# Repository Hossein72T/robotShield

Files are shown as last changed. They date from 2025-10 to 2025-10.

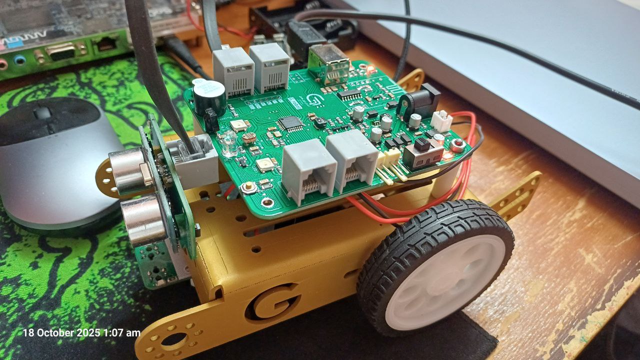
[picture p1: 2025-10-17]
docs/Ultasonic/Gro.jpg

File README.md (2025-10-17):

# Robot Shield Project

This project is part of the ZLab hardware assessment.

It includes:
- An **Arduino program** for reading distance using the **HC-SR05 ultrasonic sensor**
- A **custom library** written without using any external ultrasonic libraries
- A **PCB design** created in **Altium Designer** based on the **ATmega328** microcontroller

---

## Tools Used
- Arduino IDE  
- Altium Designer  

---

## Project Structure
```
robotShield/
 ├── code/           # Arduino sketches and custom library
 ├── pcb/            # Altium schematic and PCB files
 ├── docs/           # Report and screenshots
 └── README.md
```

---

## Project Contents
- `code/` → Arduino code and ultrasonic sensor library  
- `pcb/` → Altium schematic and PCB files  
- `docs/` → Report and related images  
- `README.md` → This file

---

Author: **Hossein Taghiloo**

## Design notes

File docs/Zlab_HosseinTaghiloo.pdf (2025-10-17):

گزارش عملکرد پروژههای ارزیابی

نام :حسین تقیلو
تاریخ :مهر ۱۴۰۴

۱ .راهاندازی سنسور اولتراسونیک05SRF

در این بخش، هدف راهاندازی و تست سنسور فاصلهسنج 05SRFبدون استفاده از الیبرری های آماده بود.

برای این منظور، یک کتابخانه اختصاصی با زبان ++C طراحی و پیادهسازی شد که شامل سه تابع اصلی است:

- ()getDistanceبرای محاسبه فاصله بر حسب سانتیمتر
- (thresholdCM(isObjectDetectedبرای تشخیص وجود جسم در فاصله مشخص
- ()getFilteredDistanceبرای میانگینگیری چند نمونه و کاهش نویز

کد در محیط IDE Arduinoنوشته و روی ربات GROکه خودم طراحی کردهام، تست عملی انجام شد. نتایج اندازهگیری دقیق و پایدار بودند و عملکرد سنسور در محدوده ۱۰ تا ۱۰۰ سانتیمتر بهدرستی تأیید شد.

کلیهی فایلهای مربوط به این بخش شامل کد منبع، فایلهای ino،. h.و cpp.در مخزن گیتهاب زیر قرار داده شدهاند: github.com/Hossein72T/robotShield

۲ .طراحی مدار و PCB شیلد ربات

در بخش دوم، طراحی مدار و برد مربوط به شیلد ربات انجام شد. برد بر پایهی میکروکنترلر P328ATmega طراحی شده تا از طریق IDE Arduinoقابل برنامهریزی باشد.

مدار شامل بخشهای زیر است:

- مدار تغذیه ۱۲ ولت با رگوالتور ۵ ولت
- کلید روشن/خاموش و ۵ دکمه فشاری برای کنترل حالتها
- نمایشگر OLED جهت نمایش وضعیت ها
- بازر ۵ ولتی برای هشدار صوتی
- ورودی سنسور و خروجی های کنترلی برای موتور و ماژولها

با توجه به محدودیت زمان، مسیرکشی برد بهصورت دستی انجام نشد و از قابلیت Route Autoنرمافزار Altium Designerاستفاده گردید.

با این حال، طراحی شماتیک، نتنامها، اتصاالت و ماژولهای مدار بهصورت کامل انجام شده و آمادهی ویرایش یا بازطراحی دستی هستند.

فایلهای پروژه شامل موارد زیر در مخزن گیتهاب در دسترس هستند: robotShield.PrjPcb, robotShield.PcbDoc, robotShield_CPU.SchDoc, وrobotShield_Power.SchDoc, robotShield_OLED.SchDoc, robotShield_USB.SchDoc robotShield_Buttom.SchDoc

۳ .جمعبندی

هر دو تسک خواسته شده مطابق شرح پروژه انجام و مستند شدند:

- پیادهسازی و تست موفق سنسور 05SRF بر روی ربات طراحیشده
- طراحی کامل مدار و برد شیلد ربات درDesigner Altium
- استفاده از Routing Auto بهدلیل محدودیت زمانی

تمامی فایلها و کدها از طریق مخزن زیر قابل مشاهده هستند: https://github.com/Hossein72T/robotShield

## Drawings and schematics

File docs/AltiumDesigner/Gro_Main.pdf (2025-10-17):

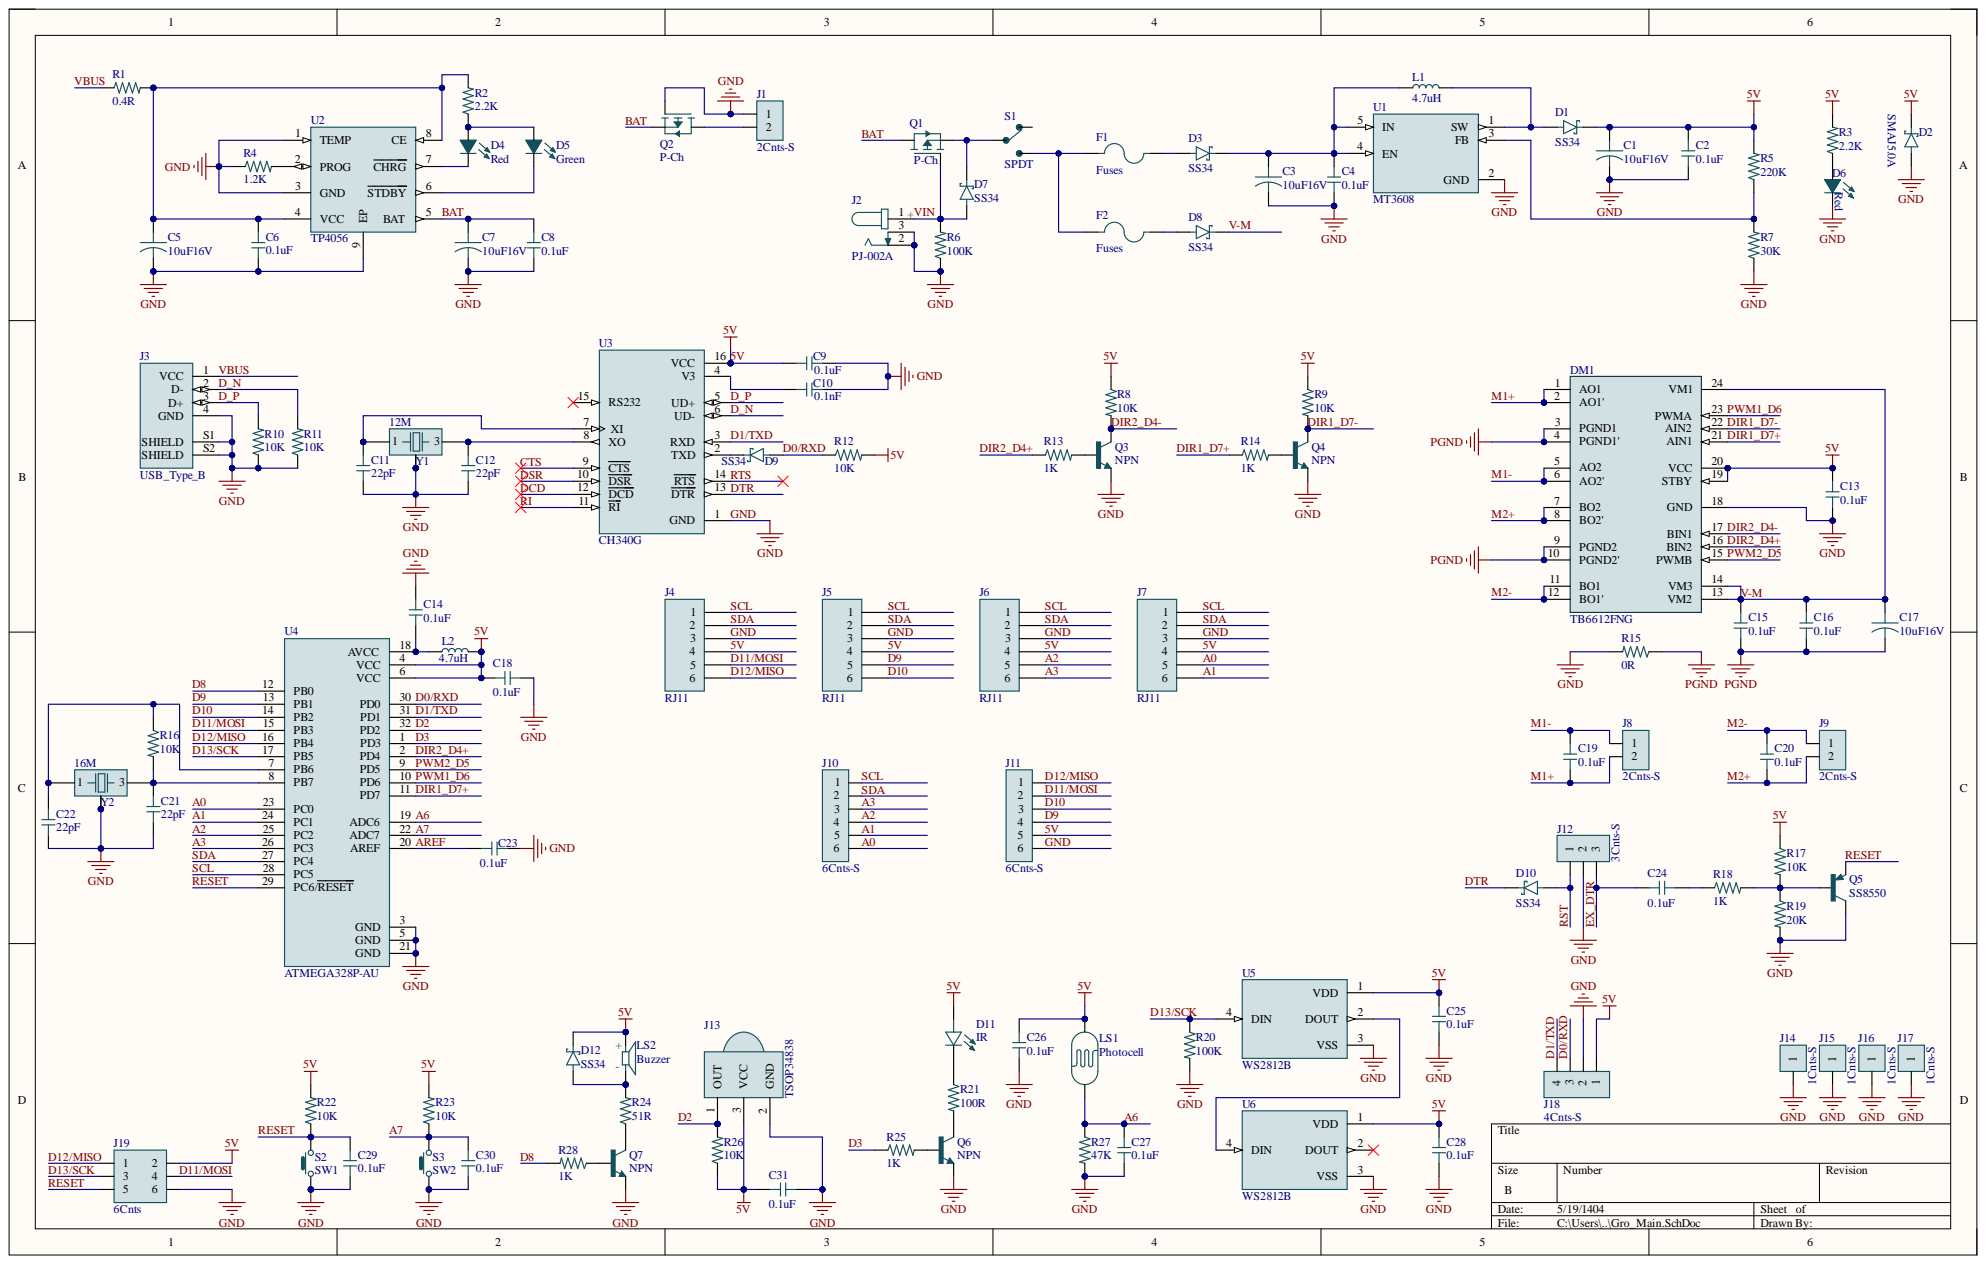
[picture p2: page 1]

SDA | SDA | SDA
GND | GND | GND

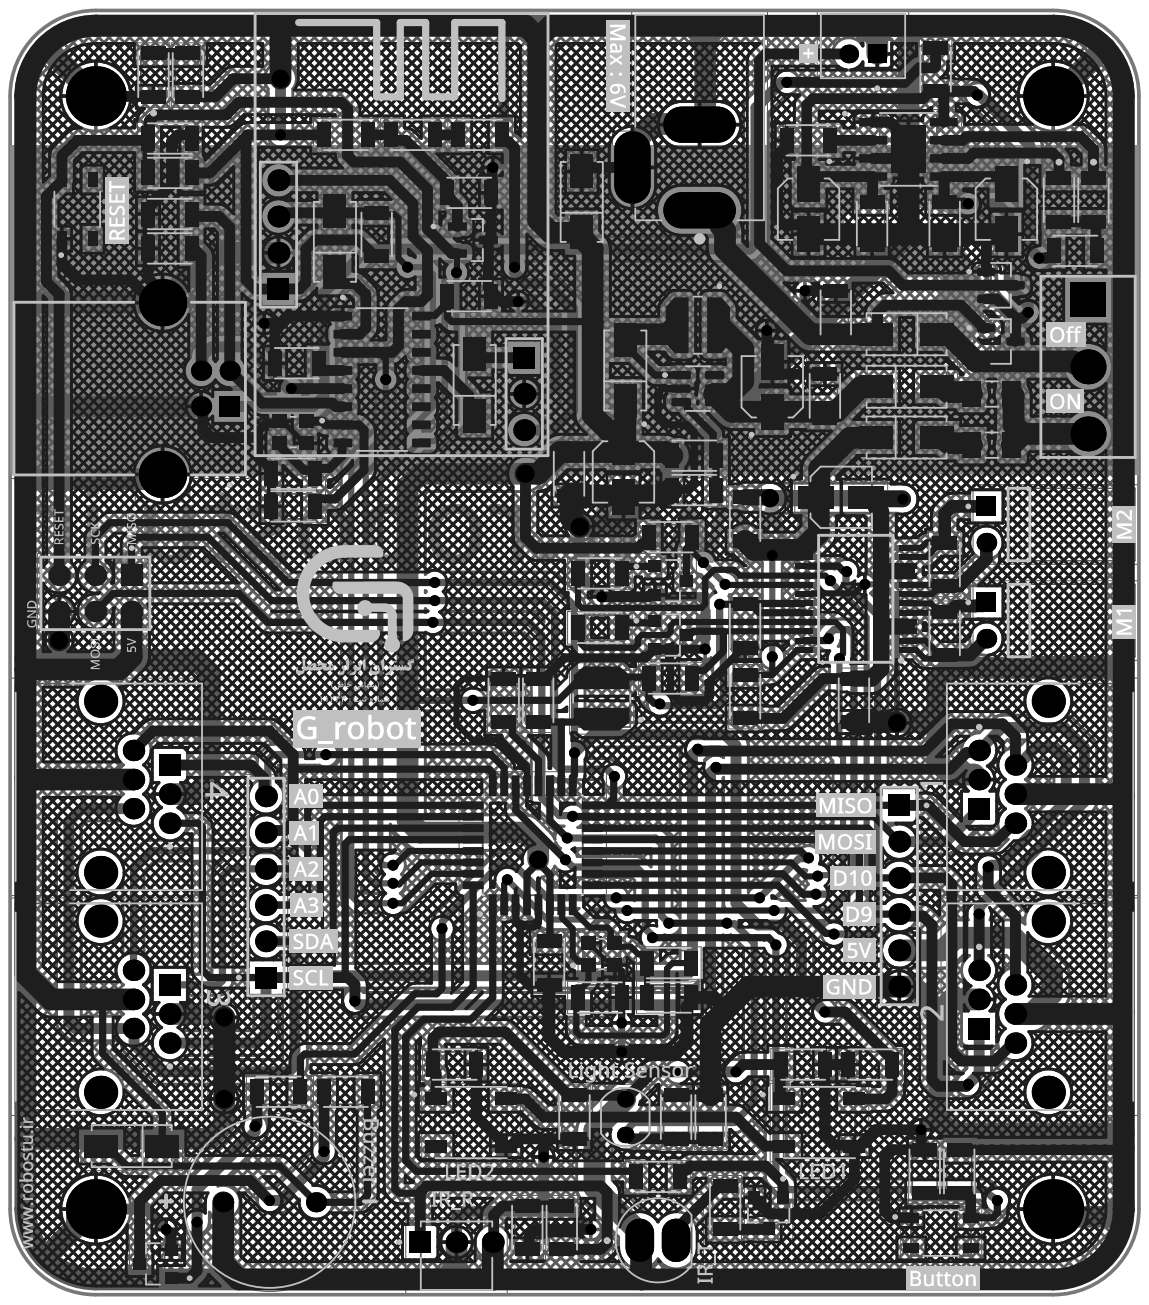
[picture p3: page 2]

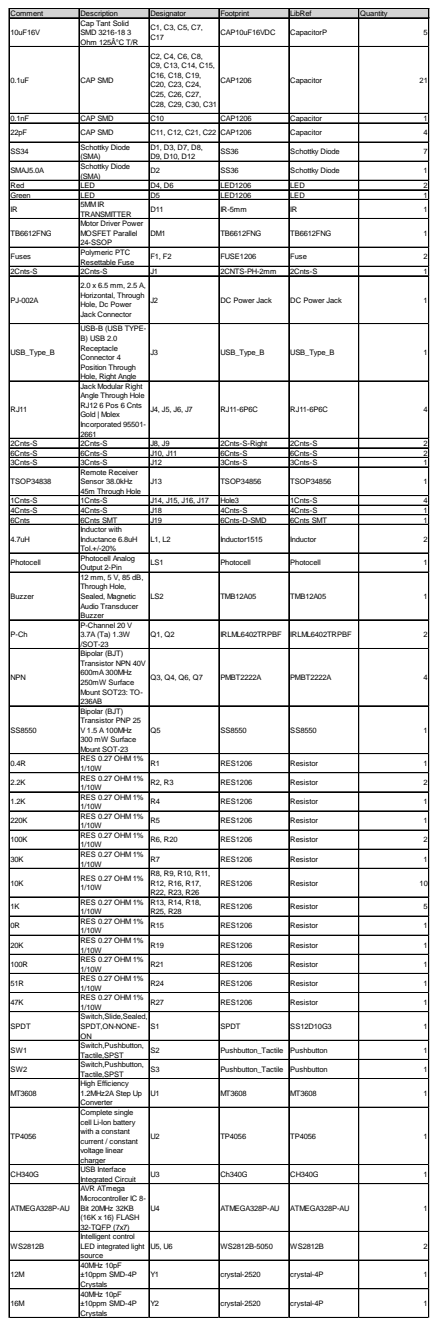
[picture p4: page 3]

Comment | Description | Designator | Footprint | LibRef | Quantity
10uF16V | Cap Tant Solid SMD 3216-18 3 Ohm 125Â°C T/R | C1, C3, C5, C7, C17 | CAP10uF16VDC | CapacitorP | 5

0.1uF | CAP SMD | C2, C4, C6, C8, C9, C13, C14, C15, C16, C18, C19, C20, C23, C24, C25, C26, C27, C28, C29, C30, C31 | CAP1206 | Capacitor | 21

0.1nF | CAP SMD | C10 | CAP1206 | Capacitor | 1

22pF | CAP SMD | C11, C12, C21, C22 | CAP1206 | Capacitor | 4

SS34 | Schottky Diode (SMA) | D1, D3, D7, D8, D9, D10, D12 | SS36 | Schottky Diode | 7

SMAJ5.0A | Schottky Diode (SMA) | D2 | SS36 | Schottky Diode | 1

Red | LED | D4, D6 | LED1206 | LED | 2
Green | LED | D5 | LED1206 | LED | 1
IR | 5MM IR TRANSMITTER | D11 | IR-5mm | IR | 1

TB6612FNG | Motor Driver Power MOSFET Parallel 24-SSOP | DM1 | TB6612FNG | TB6612FNG | 1

Fuses | Polymeric PTC Resettable Fuse | F1, F2 | FUSE1206 | Fuse | 2

2Cnts-S | 2Cnts-S | J1 | 2CNTS-PH-2mm | 2Cnts-S | 1

PJ-002A | 2.0 x 6.5 mm, 2.5 A, Horizontal, Through Hole, Dc Power Jack Connector | J2 | DC Power Jack | DC Power Jack | 1

USB_Type_B | USB-B (USB TYPE-B) USB 2.0 Receptacle Connector 4 Position Through Hole, Right Angle | J3 | USB_Type_B | USB_Type_B | 1

RJ11 | Jack Modular Right Angle Through Hole RJ12 6 Pos 6 Cnts Gold | Molex Incorporated 95501-2661 | J4, J5, J6, J7 | RJ11-6P6C | RJ11-6P6C | 4

2Cnts-S | 2Cnts-S | J8, J9 | 2Cnts-S-Right | 2Cnts-S | 2
6Cnts-S | 6Cnts-S | J10, J11 | 6Cnts-S | 6Cnts-S | 2
3Cnts-S | 3Cnts-S | J12 | 3Cnts-S | 3Cnts-S | 1
TSOP34838 | Remote Receiver Sensor 38.0kHz 45m Through Hole | J13 | TSOP34856 | TSOP34856 | 1

1Cnts-S | 1Cnts-S | J14, J15, J16, J17 | Hole3 | 1Cnts-S | 4
4Cnts-S | 4Cnts-S | J18 | 4Cnts-S | 4Cnts-S | 1
6Cnts | 6Cnts SMT | J19 | 6Cnts-D-SMD | 6Cnts SMT | 1
4.7uH | Inductor with Inductance 6.8uH Tol.+/-20% | L1, L2 | Inductor1515 | Inductor | 2

Photocell | Photocell Analog Output 2-Pin | LS1 | Photocell | Photocell | 1

Buzzer | 12 mm, 5 V, 85 dB, Through Hole, Sealed, Magnetic Audio Transducer Buzzer | LS2 | TMB12A05 | TMB12A05 | 1

P-Ch | P-Channel 20 V 3.7A (Ta) 1.3W /SOT-23 | Q1, Q2 | IRLML6402TRPBF | IRLML6402TRPBF | 2

NPN | Bipolar (BJT) Transistor NPN 40V 600mA 300MHz 250mW Surface Mount SOT23: TO-236AB | Q3, Q4, Q6, Q7 | PMBT2222A | PMBT2222A | 4

SS8550 | Bipolar (BJT) Transistor PNP 25 V 1.5 A 100MHz 300 mW Surface Mount SOT-23 | Q5 | SS8550 | SS8550 | 1

0.4R | RES 0.27 OHM 1% 1/10W | R1 | RES1206 | Resistor | 1

2.2K | RES 0.27 OHM 1% 1/10W | R2, R3 | RES1206 | Resistor | 2

1.2K | RES 0.27 OHM 1% 1/10W | R4 | RES1206 | Resistor | 1

220K | RES 0.27 OHM 1% 1/10W | R5 | RES1206 | Resistor | 1

100K | RES 0.27 OHM 1% 1/10W | R6, R20 | RES1206 | Resistor | 2

30K | RES 0.27 OHM 1% 1/10W | R7 | RES1206 | Resistor | 1

10K | RES 0.27 OHM 1% 1/10W | R8, R9, R10, R11, R12, R16, R17, R22, R23, R26 | RES1206 | Resistor | 10

1K | RES 0.27 OHM 1% 1/10W | R13, R14, R18, R25, R28 | RES1206 | Resistor | 5

0R | RES 0.27 OHM 1% 1/10W | R15 | RES1206 | Resistor | 1

20K | RES 0.27 OHM 1% 1/10W | R19 | RES1206 | Resistor | 1

100R | RES 0.27 OHM 1% 1/10W | R21 | RES1206 | Resistor | 1

51R | RES 0.27 OHM 1% 1/10W | R24 | RES1206 | Resistor | 1

47K | RES 0.27 OHM 1% 1/10W | R27 | RES1206 | Resistor | 1

SPDT | Switch,Slide,Sealed, SPDT,ON-NONE-ON | S1 | SPDT | SS12D10G3 | 1

SW1 | Switch,Pushbutton, Tactile,SPST | S2 | Pushbutton_Tactile | Pushbutton | 1

SW2 | Switch,Pushbutton, Tactile,SPST | S3 | Pushbutton_Tactile | Pushbutton | 1

MT3608 | High Efficiency 1.2MHz2A Step Up Converter | U1 | MT3608 | MT3608 | 1

TP4056 | Complete single cell Li-Ion battery with a constant current / constant voltage linear charger | U2 | TP4056 | TP4056 | 1

CH340G | USB Interface Integrated Circuit | U3 | Ch340G | CH340G | 1

ATMEGA328P-AU | AVR ATmega Microcontroller IC 8-Bit 20MHz 32KB (16K x 16) FLASH 32-TQFP (7x7) | U4 | ATMEGA328P-AU | ATMEGA328P-AU | 1

WS2812B | Intelligent control LED integrated light source | U5, U6 | WS2812B-5050 | WS2812B | 2

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

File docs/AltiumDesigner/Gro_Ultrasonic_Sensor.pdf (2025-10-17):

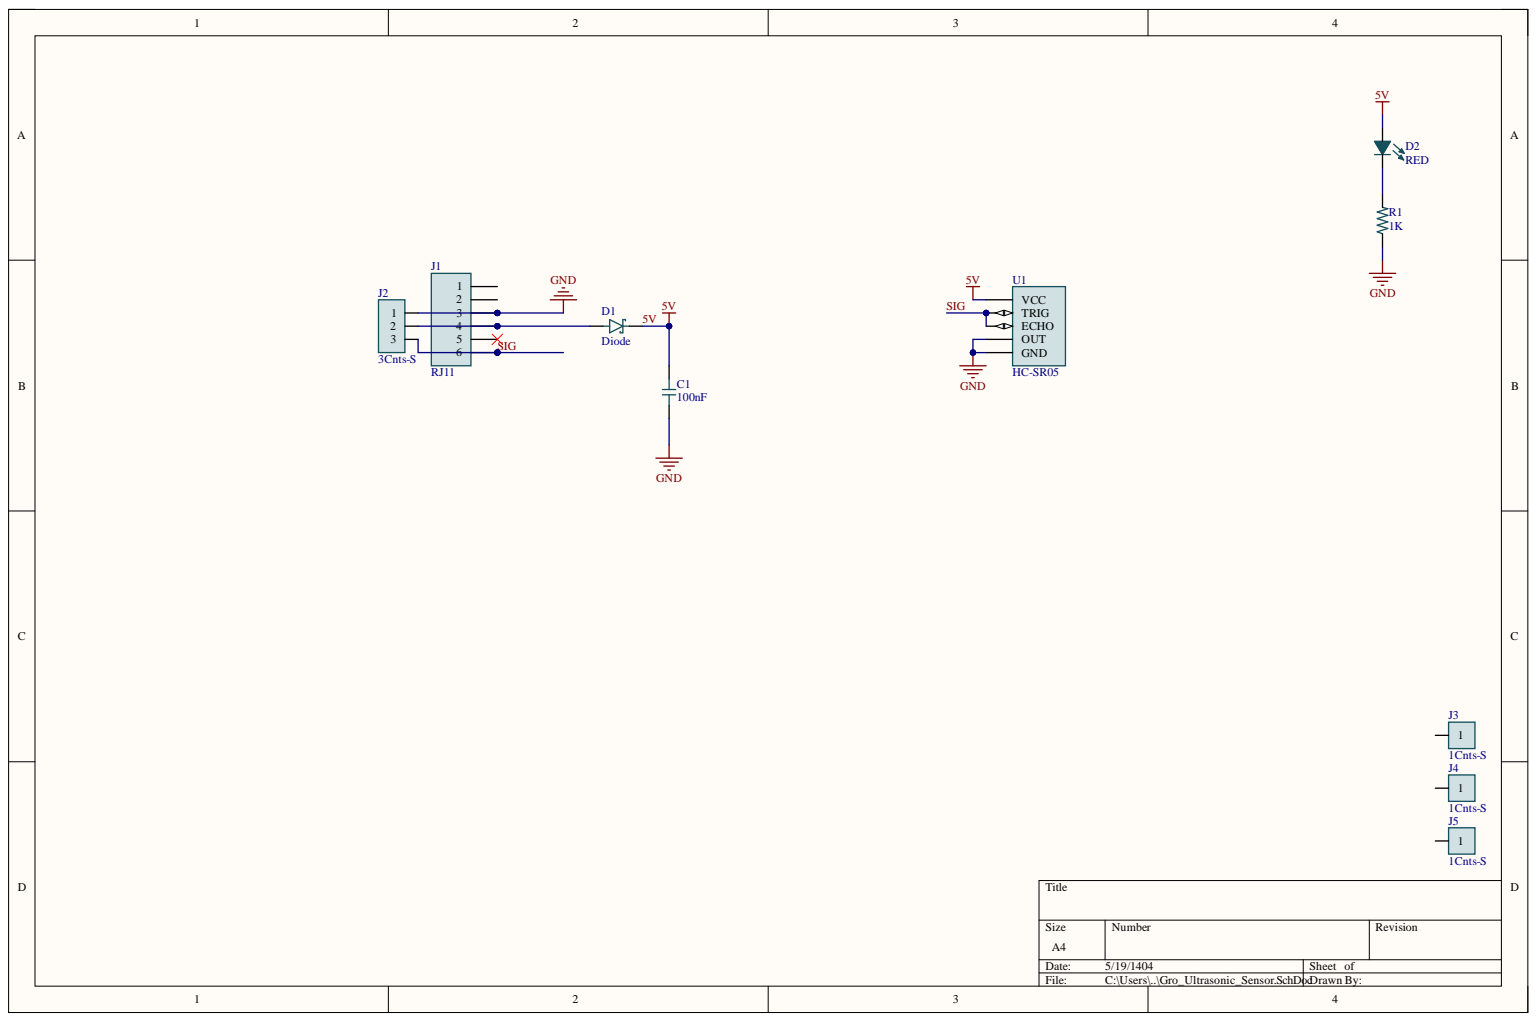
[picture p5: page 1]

VCC TRIG ECHO GND OUT

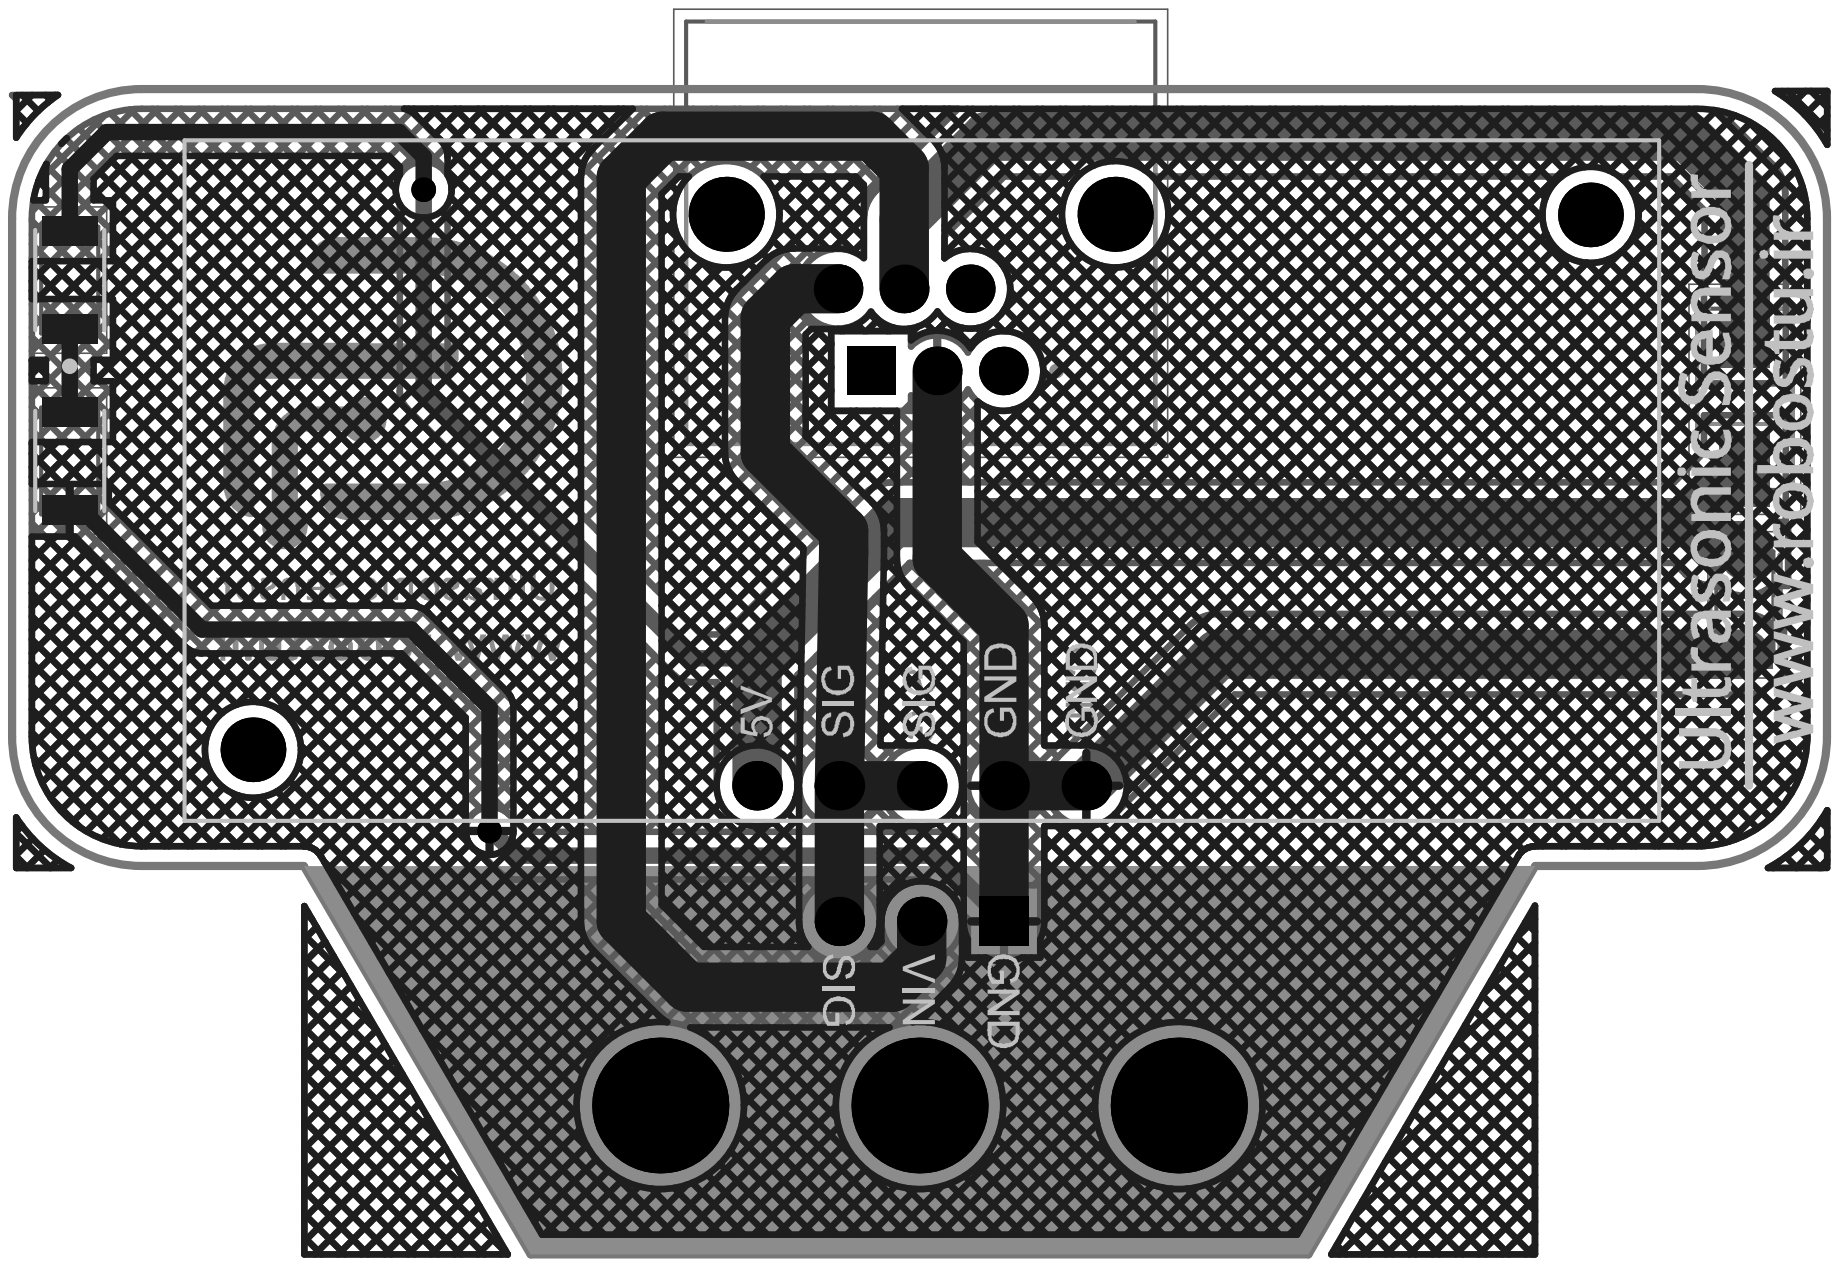
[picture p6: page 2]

Comment | Description | Designator | Footprint | LibRef | Quantity
100nF | CAP SMD | C1 | CAP1206 | Capacitor | 1
Diode | Schottky Diode | D1 | SS36 | Schottky Diode | 1
RED | LED | D2 | LED1206 | LED | 1
RJ11 | Jack Modular Right Angle Through Hole RJ12 6 Pos 6 Cnts Gold | Molex Incorporated 95501-2661 | J1 | RJ11-6P6C | RJ11-6P6C | 1
3Cnts-S | 3Cnts-S | J2 | 3Cnts-S | 3Cnts-S | 1
1Cnts-S | 1Cnts-S | J3, J4, J5 | Hole3 | 1Cnts-S | 3
1K | RES 0.27 OHM 1% 1/10W | R1 | RES1206 | Resistor | 1
HC-SR05 | Ultrasonic Sensor Module | U1 | HC-SR05 | HC-SR05 | 1

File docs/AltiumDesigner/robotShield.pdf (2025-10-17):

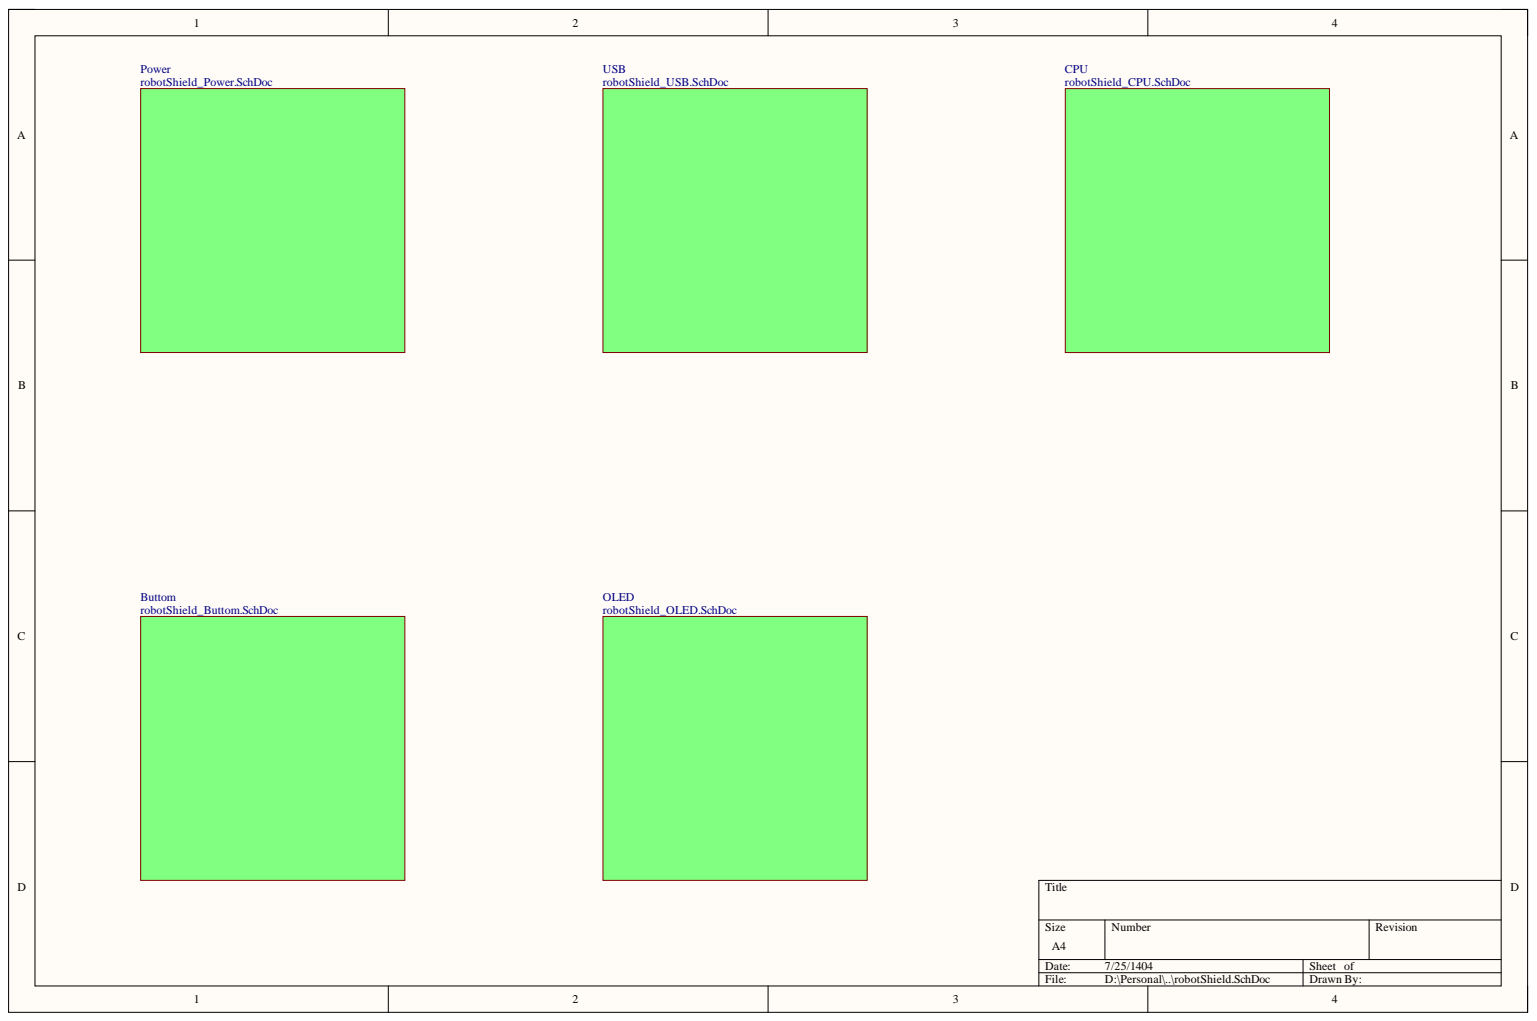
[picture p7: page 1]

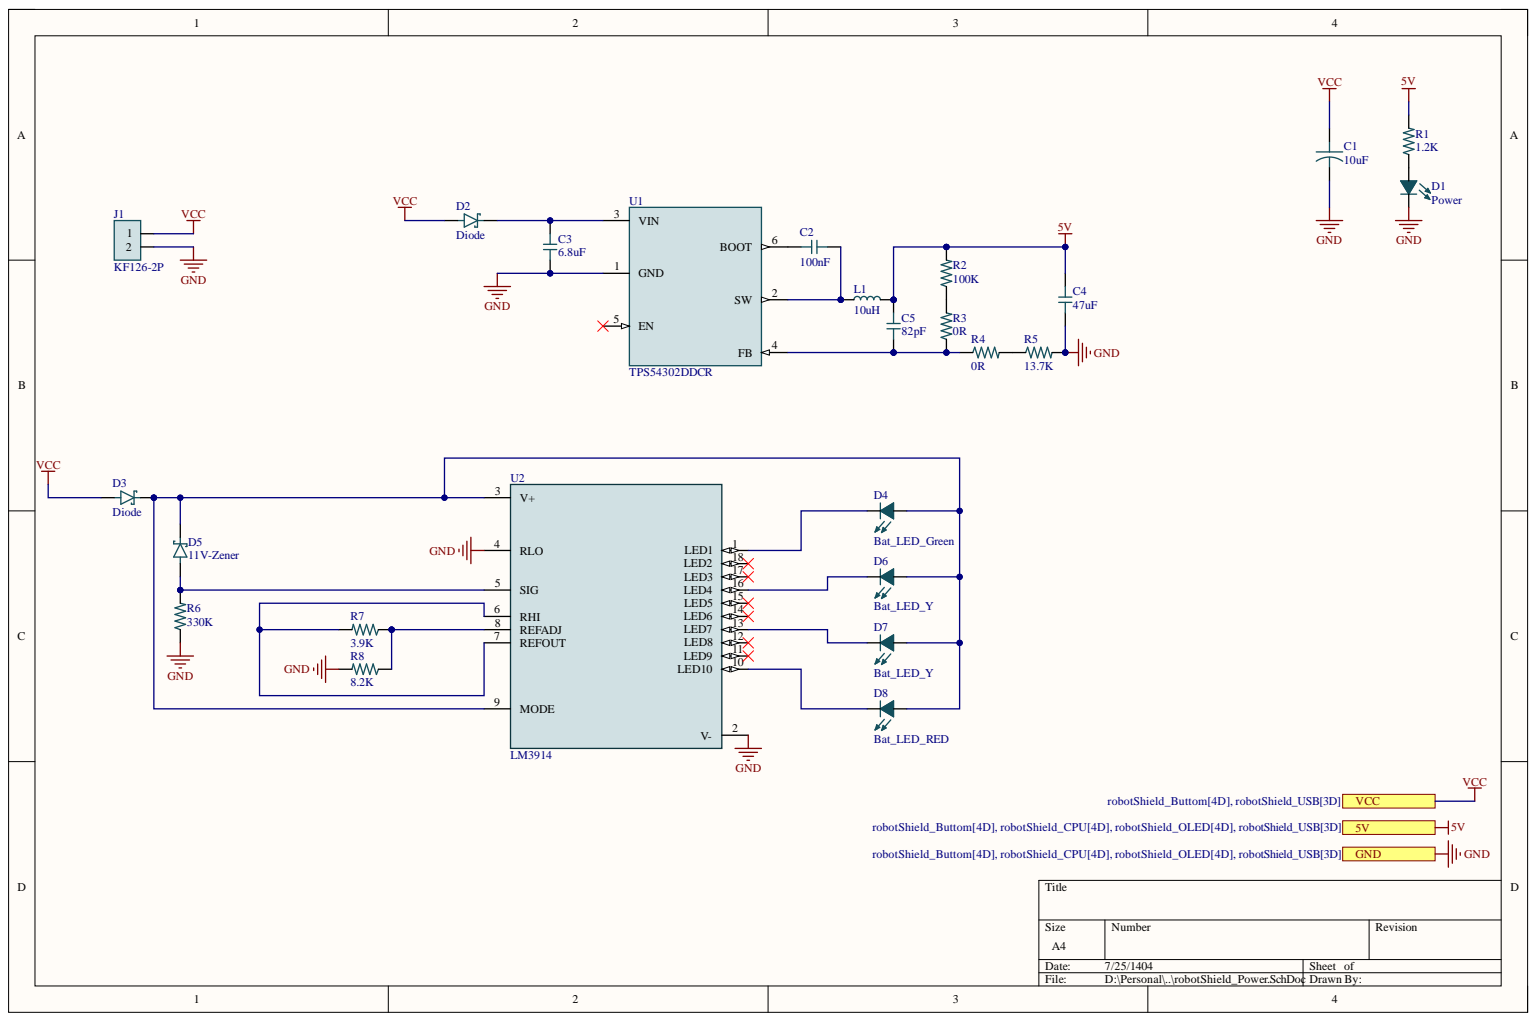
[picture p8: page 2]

5 | | 1 8

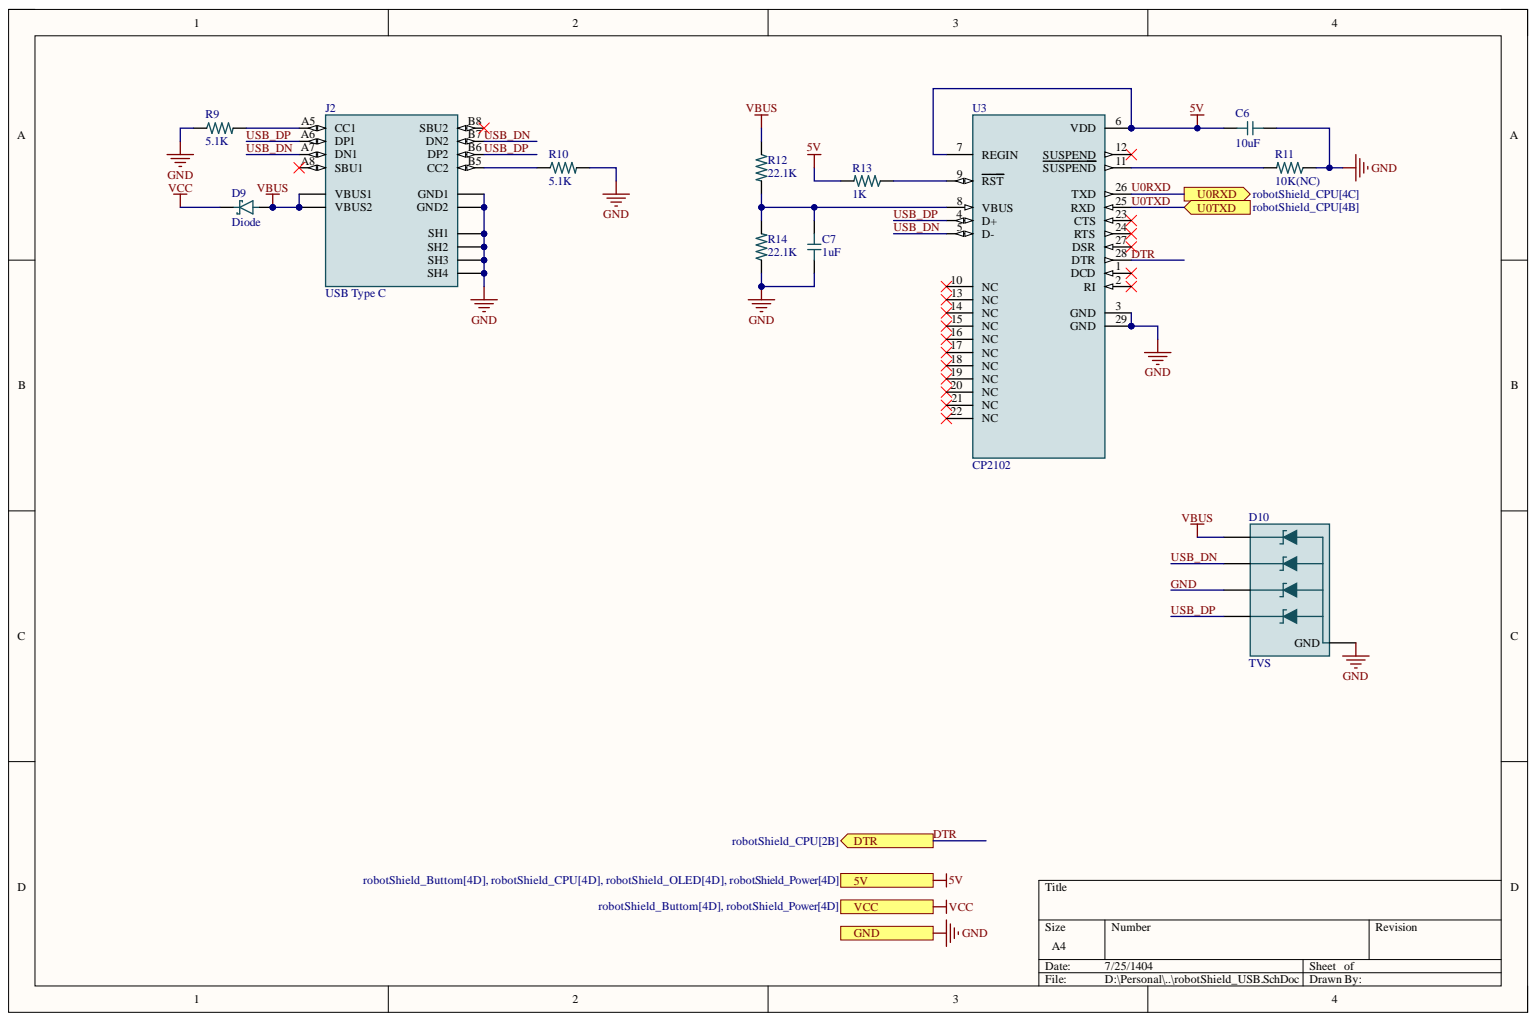
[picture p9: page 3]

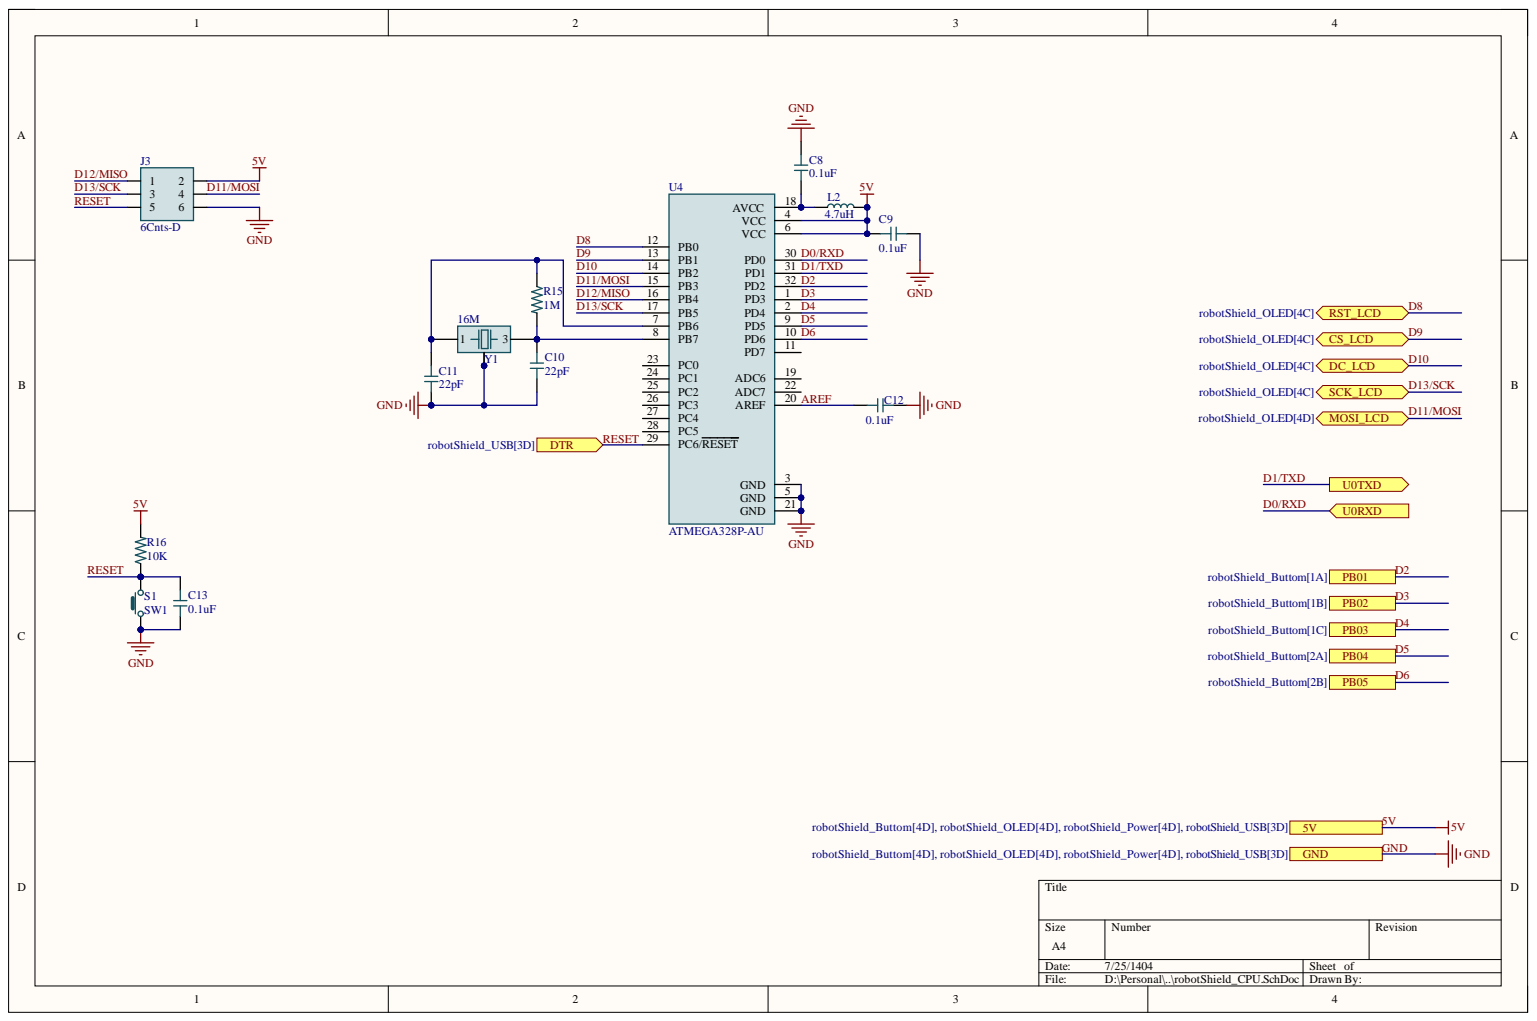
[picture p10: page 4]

4 | 4.7 u H

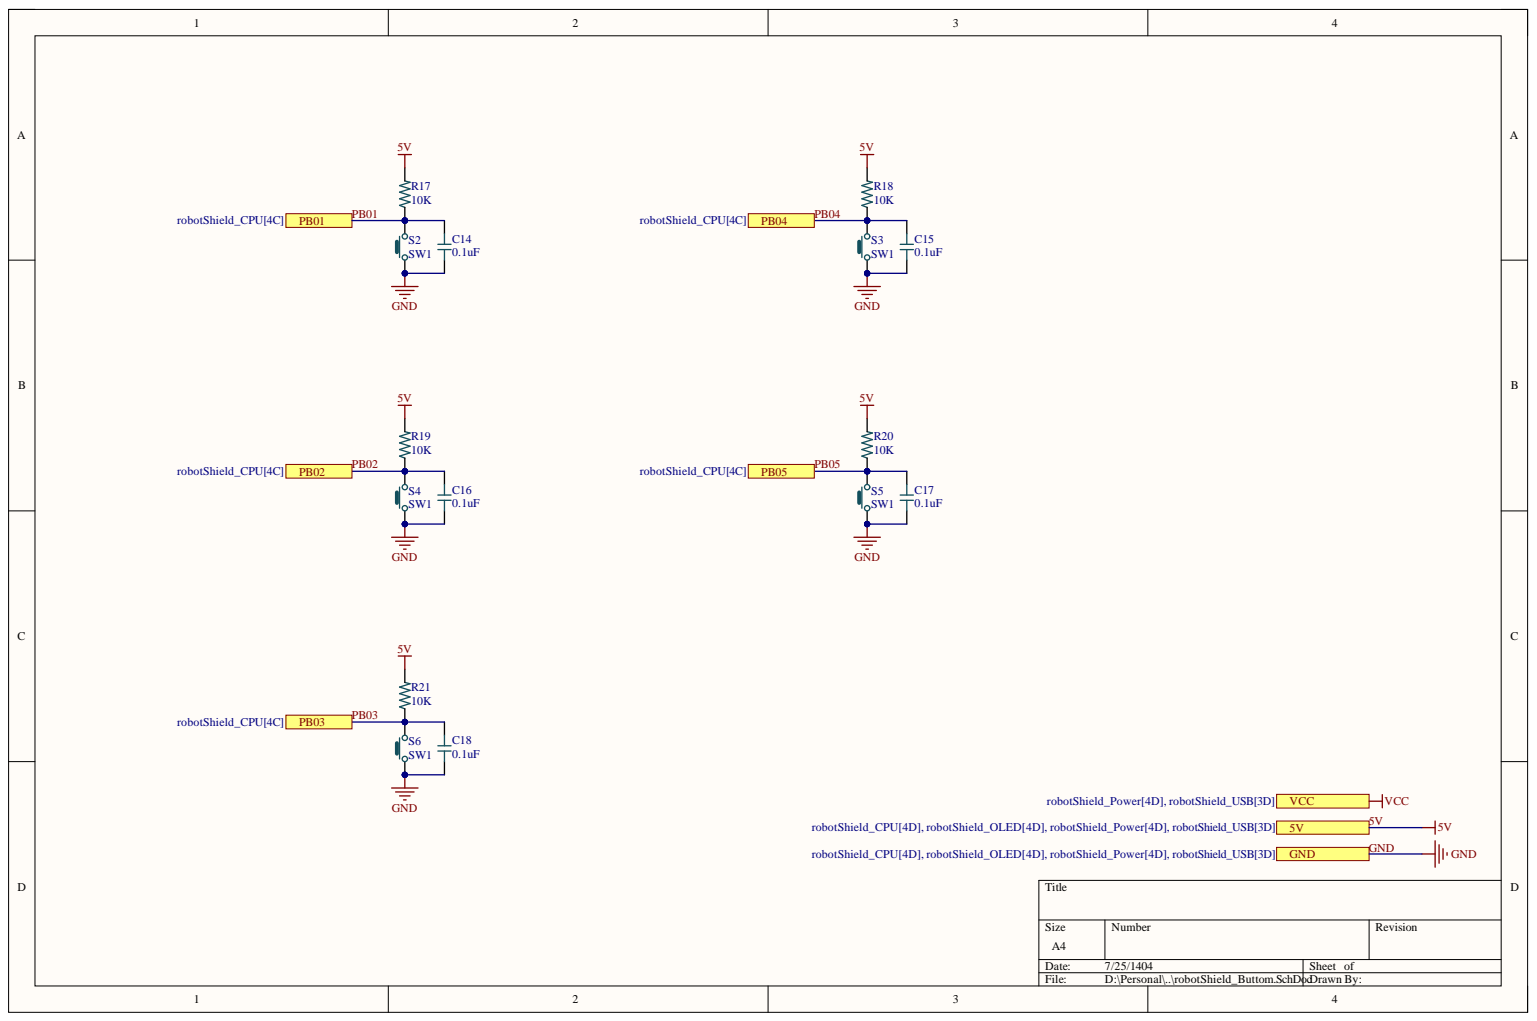
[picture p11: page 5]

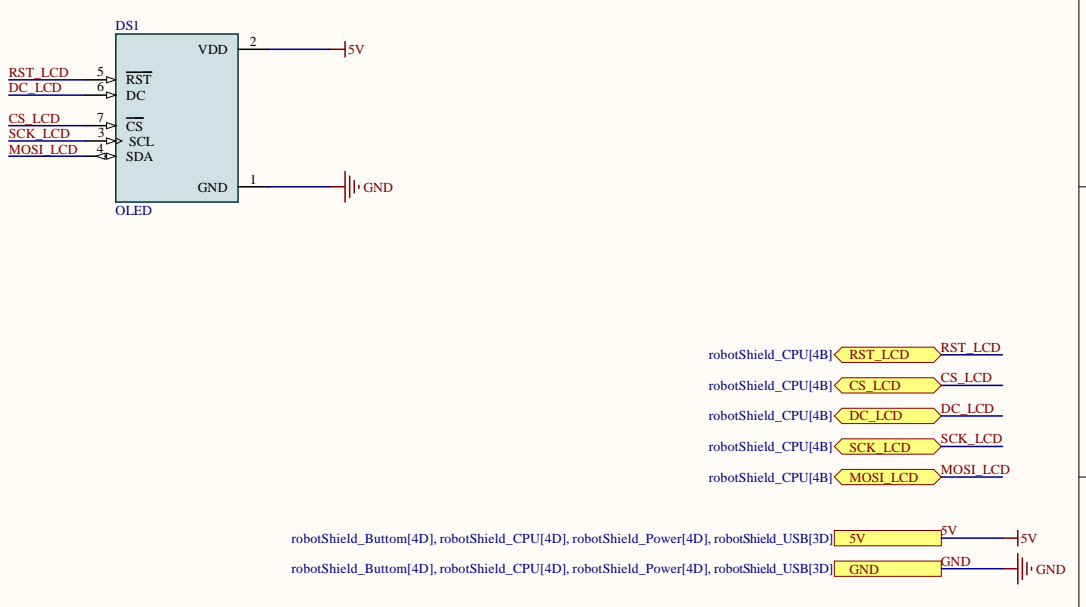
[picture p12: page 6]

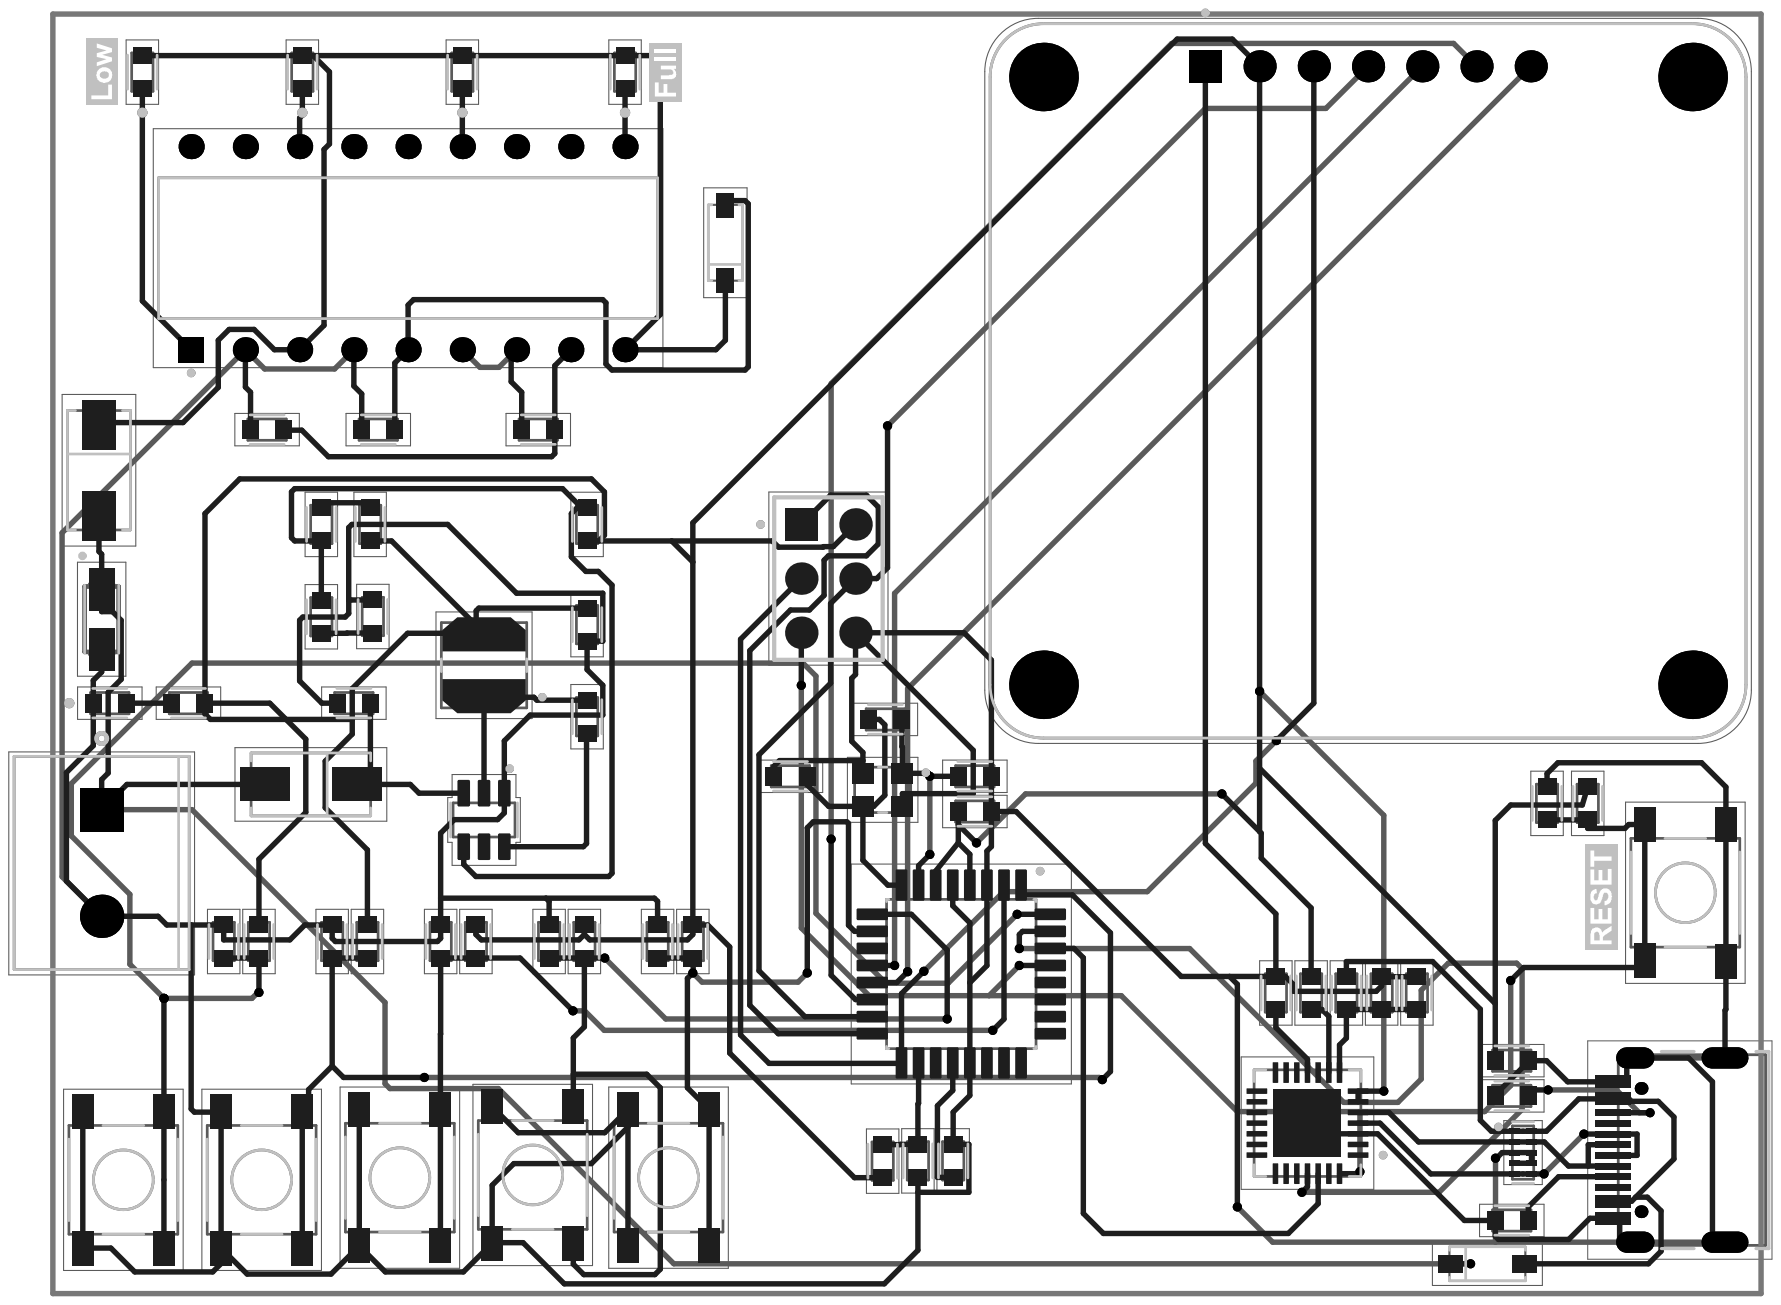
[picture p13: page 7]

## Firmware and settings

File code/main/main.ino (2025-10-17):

#include "SRF05.h"

void setup() {
  Serial.begin(9600);
}

void loop() {
  float distance = getDistance();
  Serial.print("Distance: ");
  Serial.print(distance);
  Serial.println(" cm");

  if (isObjectDetected(30)) {
    Serial.println("Object detected within 30 cm");
  } else {
    Serial.println("No object within range");
  }

  float filtered = getFilteredDistance();
  Serial.print("Filtered Distance: ");
  Serial.print(filtered);
  Serial.println(" cm");

  Serial.println("-----------------------");
  delay(1000);
}

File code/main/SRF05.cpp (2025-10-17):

#include <Arduino.h>
#include "SRF05.h"

const int trigEchoPin = A3;

float getDistance() {
  pinMode(trigEchoPin, OUTPUT);
  digitalWrite(trigEchoPin, LOW);
  delayMicroseconds(2);
  digitalWrite(trigEchoPin, HIGH);
  delayMicroseconds(10);
  digitalWrite(trigEchoPin, LOW);

  pinMode(trigEchoPin, INPUT);
  unsigned long duration = pulseIn(trigEchoPin, HIGH, 30000);

  if (duration == 0) return -1;
  return duration / 58.0;
}

bool isObjectDetected(float thresholdCM) {
  float d = getDistance();
  return (d > 0 && d <= thresholdCM);
}

float getFilteredDistance() {
  float sum = 0;
  int count = 0;

  for (int i = 0; i < 5; i++) {
    float d = getDistance();
    if (d > 0) {
      sum += d;
      count++;
    }
    delay(100);
  }

  if (count == 0) return -1;
  return sum / count;
}
